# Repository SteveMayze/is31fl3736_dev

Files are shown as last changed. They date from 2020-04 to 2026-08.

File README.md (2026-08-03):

# IS31FL3736 Development Board

This project is to develop a prototype for reviewing the IS31FL3736 12×8 DOTS MATRIX LED DRIVER WITH INDIVIDUAL AUTO BREATH FUNCTION from [Integrated Silicon Solution, Inc](www.issi.com)
 The basic goals of this project is to create a simple board with an array of RGB leds to see what is involved to control the LEDs as per the writeup in the datasheet. Things of interest will be
 
 1. Simplicity of use (firmware)
 1. Simplicity of the layout
 1. The effective power consumption
 1. The footprint size.

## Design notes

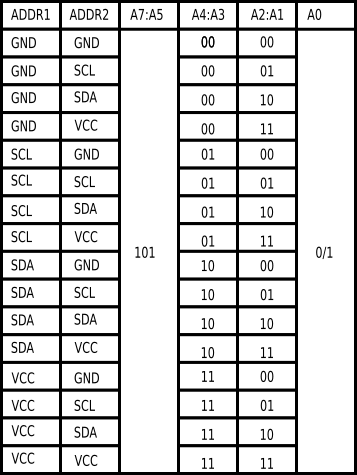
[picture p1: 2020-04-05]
Doc/AddressTable.png

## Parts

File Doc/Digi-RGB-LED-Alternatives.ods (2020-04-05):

Datenblätter | Abbildung | Digi-Key Teilenummer | Hersteller-Teilenummer | Hersteller | Beschreibung | Verfügbare Menge | Lagerbestand des Herstellers | Stückpreis (EUR) | @ qty | Mindestbestellmenge ist | Verpackung | Serie | Status der Komponente | Farbe | Konfiguration | Linsenfarbe | Linsentransparenz | Millicandela-Bewertung | Linsenstil | Linsengröße | Spannung - Forward (Vf) Typ | Strom - Test | Sichtwinkel | Montagetyp | Wellenlänge - dominant | Wellenlänge - Spitze | Funktionen | Gehäuse / Hülle | Gehäusetyp vom Lieferanten | Grösse / Dimension | Höhe (max.)
http://www.inolux-corp.com/datasheet/SMDLED/RGB%20Top%20View/IN-B101FCH.pdf | //media.digikey.com/Renders/Inolux/IN-B101FCH.JPG | 1830-1087-1-ND | IN-B101FCH | Inolux | LED RGB TOP VIEW SMD | 16764 | 0 | 0.39000 | 1 | 1 | Gurtabschnitt (CT) | - | Aktiv | Rot, Grün, Blau (RGB) | GemeinsameAnode | - | - | 58mcd Rot, 85mcd Grün, 17mcd Blau | Quadratisch mit flachem Oberteil | 1,00mm | 2,4V Rot, 3,4V Grün, 3,4V Blau | 10mA Rot, 10mA Grün, 10mA Blau | 140° | Oberflächenmontage | 621nm Rot, 531nm Grün, 470nm Blau | 629nm Rot, 520nm Grün, 480nm Blau | - | 0404 (1010 metrisch) | SMD | L x B: 1,00mm x 1,00mm | 0,75mm
http://www.inolux-corp.com/datasheet/SMDLED/RGB%20Top%20View/IN-B101FCH.pdf | //media.digikey.com/Renders/Inolux/IN-B101FCH.JPG | 1830-1087-6-ND | IN-B101FCH | Inolux | LED RGB TOP VIEW SMD | 16764 | 0 | Digi-Reel | 1 | 1 | Digi-Reel® | - | Aktiv | Rot, Grün, Blau (RGB) | GemeinsameAnode | - | - | 58mcd Rot, 85mcd Grün, 17mcd Blau | Quadratisch mit flachem Oberteil | 1,00mm | 2,4V Rot, 3,4V Grün, 3,4V Blau | 10mA Rot, 10mA Grün, 10mA Blau | 140° | Oberflächenmontage | 621nm Rot, 531nm Grün, 470nm Blau | 629nm Rot, 520nm Grün, 480nm Blau | - | 0404 (1010 metrisch) | SMD | L x B: 1,00mm x 1,00mm | 0,75mm
http://www.qt-brightek.com/datasheet/QBLP1515B-RGBA.pdf | //media.digikey.com/Renders/QT%20Brightek%20Renders/1516-1183-6.jpg | 1516-1183-1-ND | QBLP1515B-RGBA | QT Brightek (QTB) | LED RGB DIFFUSED 4PLCC SMD | 13659 | 0 | 0.79000 | 1 | 1 | Gurtabschnitt (CT) | - | Aktiv | Rot, Grün, Blau (RGB) | GemeinsameAnode | - | Diffundiert | 150mcd Rot, 300mcd Grün, 77mcd Blau | Quadratisch mit flachem Oberteil | - | 2V Rot, 3,1V Grün, 3,1V Blau | 10mA Rot, 10mA Grün, 10mA Blau | 120° | Oberflächenmontage | 622nm Rot, 523nm Grün, 467nm Blau | - | - | 4-SMD, J-Anschluss | 4-PLCC | L x B: 1,60mm x 1,50mm | 1,20mm
http://www.qt-brightek.com/datasheet/QBLP1515B-RGBA.pdf | //media.digikey.com/Renders/QT%20Brightek%20Renders/1516-1183-6.jpg | 1516-1183-6-ND | QBLP1515B-RGBA | QT Brightek (QTB) | LED RGB DIFFUSED 4PLCC SMD | 13659 | 0 | Digi-Reel | 1 | 1 | Digi-Reel® | - | Aktiv | Rot, Grün, Blau (RGB) | GemeinsameAnode | - | Diffundiert | 150mcd Rot, 300mcd Grün, 77mcd Blau | Quadratisch mit flachem Oberteil | - | 2V Rot, 3,1V Grün, 3,1V Blau | 10mA Rot, 10mA Grün, 10mA Blau | 120° | Oberflächenmontage | 622nm Rot, 523nm Grün, 467nm Blau | - | - | 4-SMD, J-Anschluss | 4-PLCC | L x B: 1,60mm x 1,50mm | 1,20mm
https://docs.broadcom.com/docs/HSMF-C129-DS100 | - | 516-4371-1-ND | HSMF-C129 | Broadcom Limited | LED RGB TOP MNT 0805 SMD | 5779 | 0 | 1.61000 | 1 | 1 | Gurtabschnitt (CT) | - | Aktiv | Rot, Grün, Blau (RGB) | GemeinsameAnode | - | - | - | Rechteckig mit flachem Oberteil | 1,40mm x 1,30mm | 2V Rot, 3,4V Grün, 3,4V Blau | 10mA Rot, 10mA Grün, 10mA Blau | 140° | Oberflächenmontage | 623nm Rot, 529nm Grün, 468nm Blau | 633nm Rot, 521nm Grün, 463nm Blau | - | 0805 (2012 metrisch) | 0805 | L x B: 2,00mm x 1,30mm | 0,60mm
https://docs.broadcom.com/docs/HSMF-C129-DS100 | - | 516-4371-6-ND | HSMF-C129 | Broadcom Limited | LED RGB TOP MNT 0805 SMD | 5779 | 0 | Digi-Reel | 1 | 1 | Digi-Reel® | - | Aktiv | Rot, Grün, Blau (RGB) | GemeinsameAnode | - | - | - | Rechteckig mit flachem Oberteil | 1,40mm x 1,30mm | 2V Rot, 3,4V Grün, 3,4V Blau | 10mA Rot, 10mA Grün, 10mA Blau | 140° | Oberflächenmontage | 623nm Rot, 529nm Grün, 468nm Blau | 633nm Rot, 521nm Grün, 463nm Blau | - | 0805 (2012 metrisch) | 0805 | L x B: 2,00mm x 1,30mm | 0,60mm
https://docs.broadcom.com/docs/HSMF-C125-DS100 | - | 516-4374-1-ND | HSMF-C125 | Broadcom Limited | LED RGB CHIP TOP MNT SMD | 5990 | 0 | 1.66000 | 1 | 1 | Gurtabschnitt (CT) | - | Aktiv | Rot, Grün, Blau (RGB) | Unabhängig | - | - | - | Rechteckig mit flachem Oberteil | 1,60mm x 1,15mm | 2,15V Rot, 3,415V Grün, 3,425V Blau | 10mA Rot, 10mA Grün, 10mA Blau | 130° Rot, 150° Grün, 150° Blau | Oberflächenmontage | 623nm Rot, 522nm Grün, 467nm Blau | 630nm Rot, 515nm Grün, 461nm Blau | - | 0606, konvex | - | L x B: 1,60mm x 1,60mm | 0,50mm
https://docs.broadcom.com/docs/HSMF-C125-DS100 | - | 516-4374-6-ND | HSMF-C125 | Broadcom Limited | LED RGB CHIP TOP MNT SMD | 5990 | 0 | Digi-Reel | 1 | 1 | Digi-Reel® | - | Aktiv | Rot, Grün, Blau (RGB) | Unabhängig | - | - | - | Rechteckig mit flachem Oberteil | 1,60mm x 1,15mm | 2,15V Rot, 3,415V Grün, 3,425V Blau | 10mA Rot, 10mA Grün, 10mA Blau | 130° Rot, 150° Grün, 150° Blau | Oberflächenmontage | 623nm Rot, 522nm Grün, 467nm Blau | 630nm Rot, 515nm Grün, 461nm Blau | - | 0606, konvex | - | L x B: 1,60mm x 1,60mm | 0,50mm
http://www.qt-brightek.com/datasheet/QBLP1515B-RGBA.pdf | //media.digikey.com/Renders/QT%20Brightek%20Renders/1516-1183-6.jpg | 1516-1183-2-ND | QBLP1515B-RGBA | QT Brightek (QTB) | LED RGB DIFFUSED 4PLCC SMD | 10500 | 0 | 0.23585 | 0 | 3500 | Gurt auf Rolle (Tape and Reel - TR) | - | Aktiv | Rot, Grün, Blau (RGB) | GemeinsameAnode | - | Diffundiert | 150mcd Rot, 300mcd Grün, 77mcd Blau | Quadratisch mit flachem Oberteil | - | 2V Rot, 3,1V Grün, 3,1V Blau | 10mA Rot, 10mA Grün, 10mA Blau | 120° | Oberflächenmontage | 622nm Rot, 523nm Grün, 467nm Blau | - | - | 4-SMD, J-Anschluss | 4-PLCC | L x B: 1,60mm x 1,50mm | 1,20mm
https://docs.broadcom.com/docs/HSMF-C125-DS100 | - | 516-4374-2-ND | HSMF-C125 | Broadcom Limited | LED RGB CHIP TOP MNT SMD | 4000 | 0 | 0.55045 | 0 | 2000 | Gurt auf Rolle (Tape and Reel - TR) | - | Aktiv | Rot, Grün, Blau (RGB) | Unabhängig | - | - | - | Rechteckig mit flachem Oberteil | 1,60mm x 1,15mm | 2,15V Rot, 3,415V Grün, 3,425V Blau | 10mA Rot, 10mA Grün, 10mA Blau | 130° Rot, 150° Grün, 150° Blau | Oberflächenmontage | 623nm Rot, 522nm Grün, 467nm Blau | 630nm Rot, 515nm Grün, 461nm Blau | - | 0606, konvex | - | L x B: 1,60mm x 1,60mm | 0,50mm
https://docs.broadcom.com/docs/HSMF-C129-DS100 | - | 516-4371-2-ND | HSMF-C129 | Broadcom Limited | LED RGB TOP MNT 0805 SMD | 4000 | 0 | 0.59781 | 0 | 2000 | Gurt auf Rolle (Tape and Reel - TR) | - | Aktiv | Rot, Grün, Blau (RGB) | GemeinsameAnode | - | - | - | Rechteckig mit flachem Oberteil | 1,40mm x 1,30mm | 2V Rot, 3,4V Grün, 3,4V Blau | 10mA Rot, 10mA Grün, 10mA Blau | 140° | Oberflächenmontage | 623nm Rot, 529nm Grün, 468nm Blau | 633nm Rot, 521nm Grün, 463nm Blau | - | 0805 (2012 metrisch) | 0805 | L x B: 2,00mm x 1,30mm | 0,60mm

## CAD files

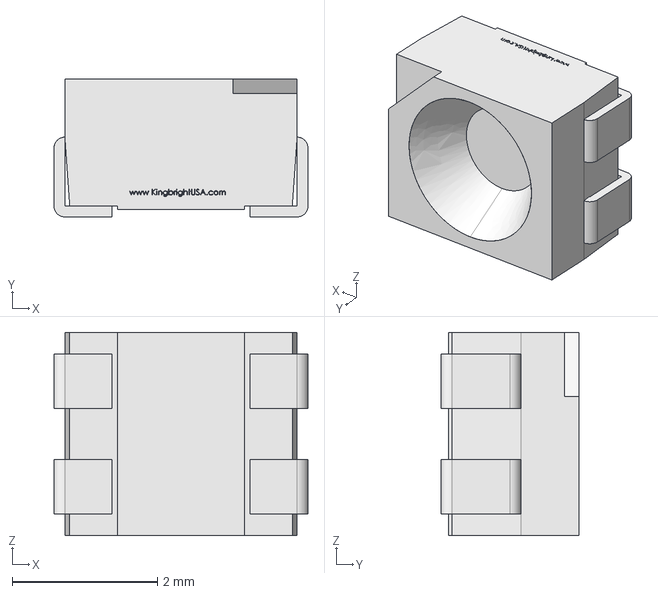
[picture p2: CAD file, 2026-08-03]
Doc/3d/xx.step
3.50 x 1.90 x 2.80 mm

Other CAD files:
Doc/3d/AAA3528.sldprt
Doc/3d/AAA3528.FCStd
Doc/3d/AAA3528.IGS

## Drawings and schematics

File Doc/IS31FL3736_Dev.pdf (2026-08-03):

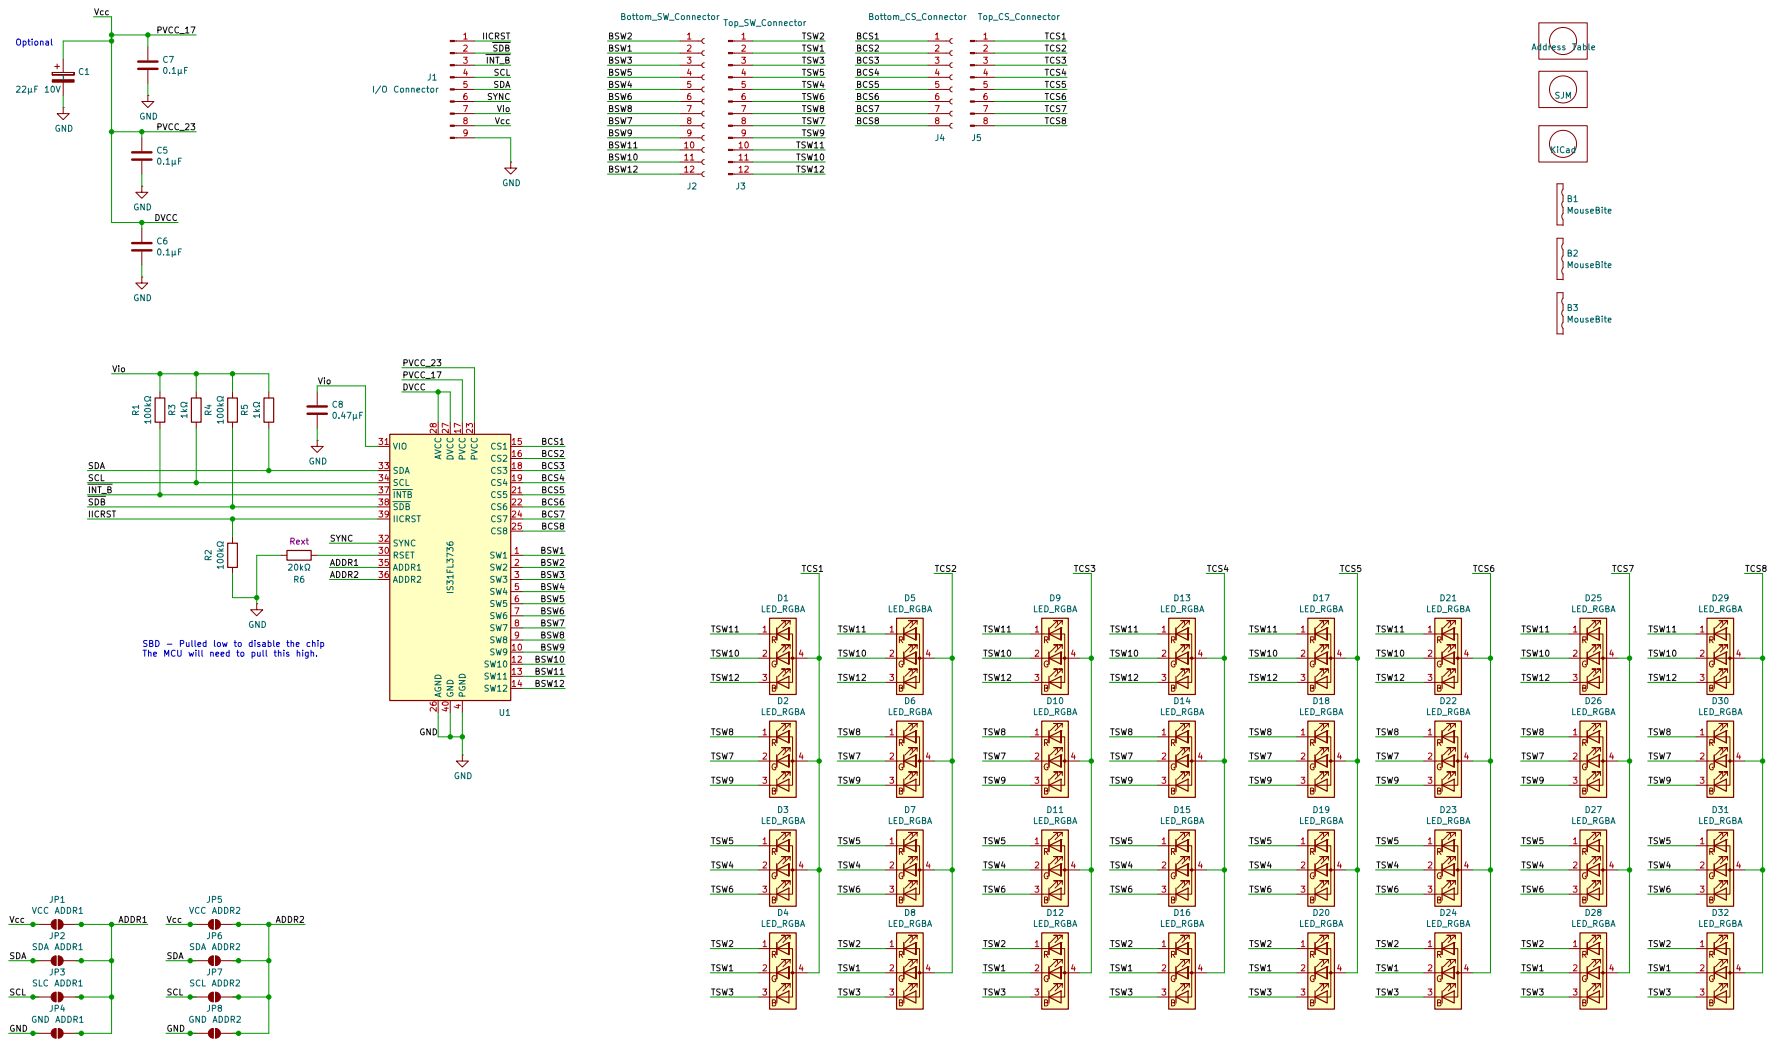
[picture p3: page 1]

SBD - Pulled low to disable the chip
The MCU will need to pull this high.

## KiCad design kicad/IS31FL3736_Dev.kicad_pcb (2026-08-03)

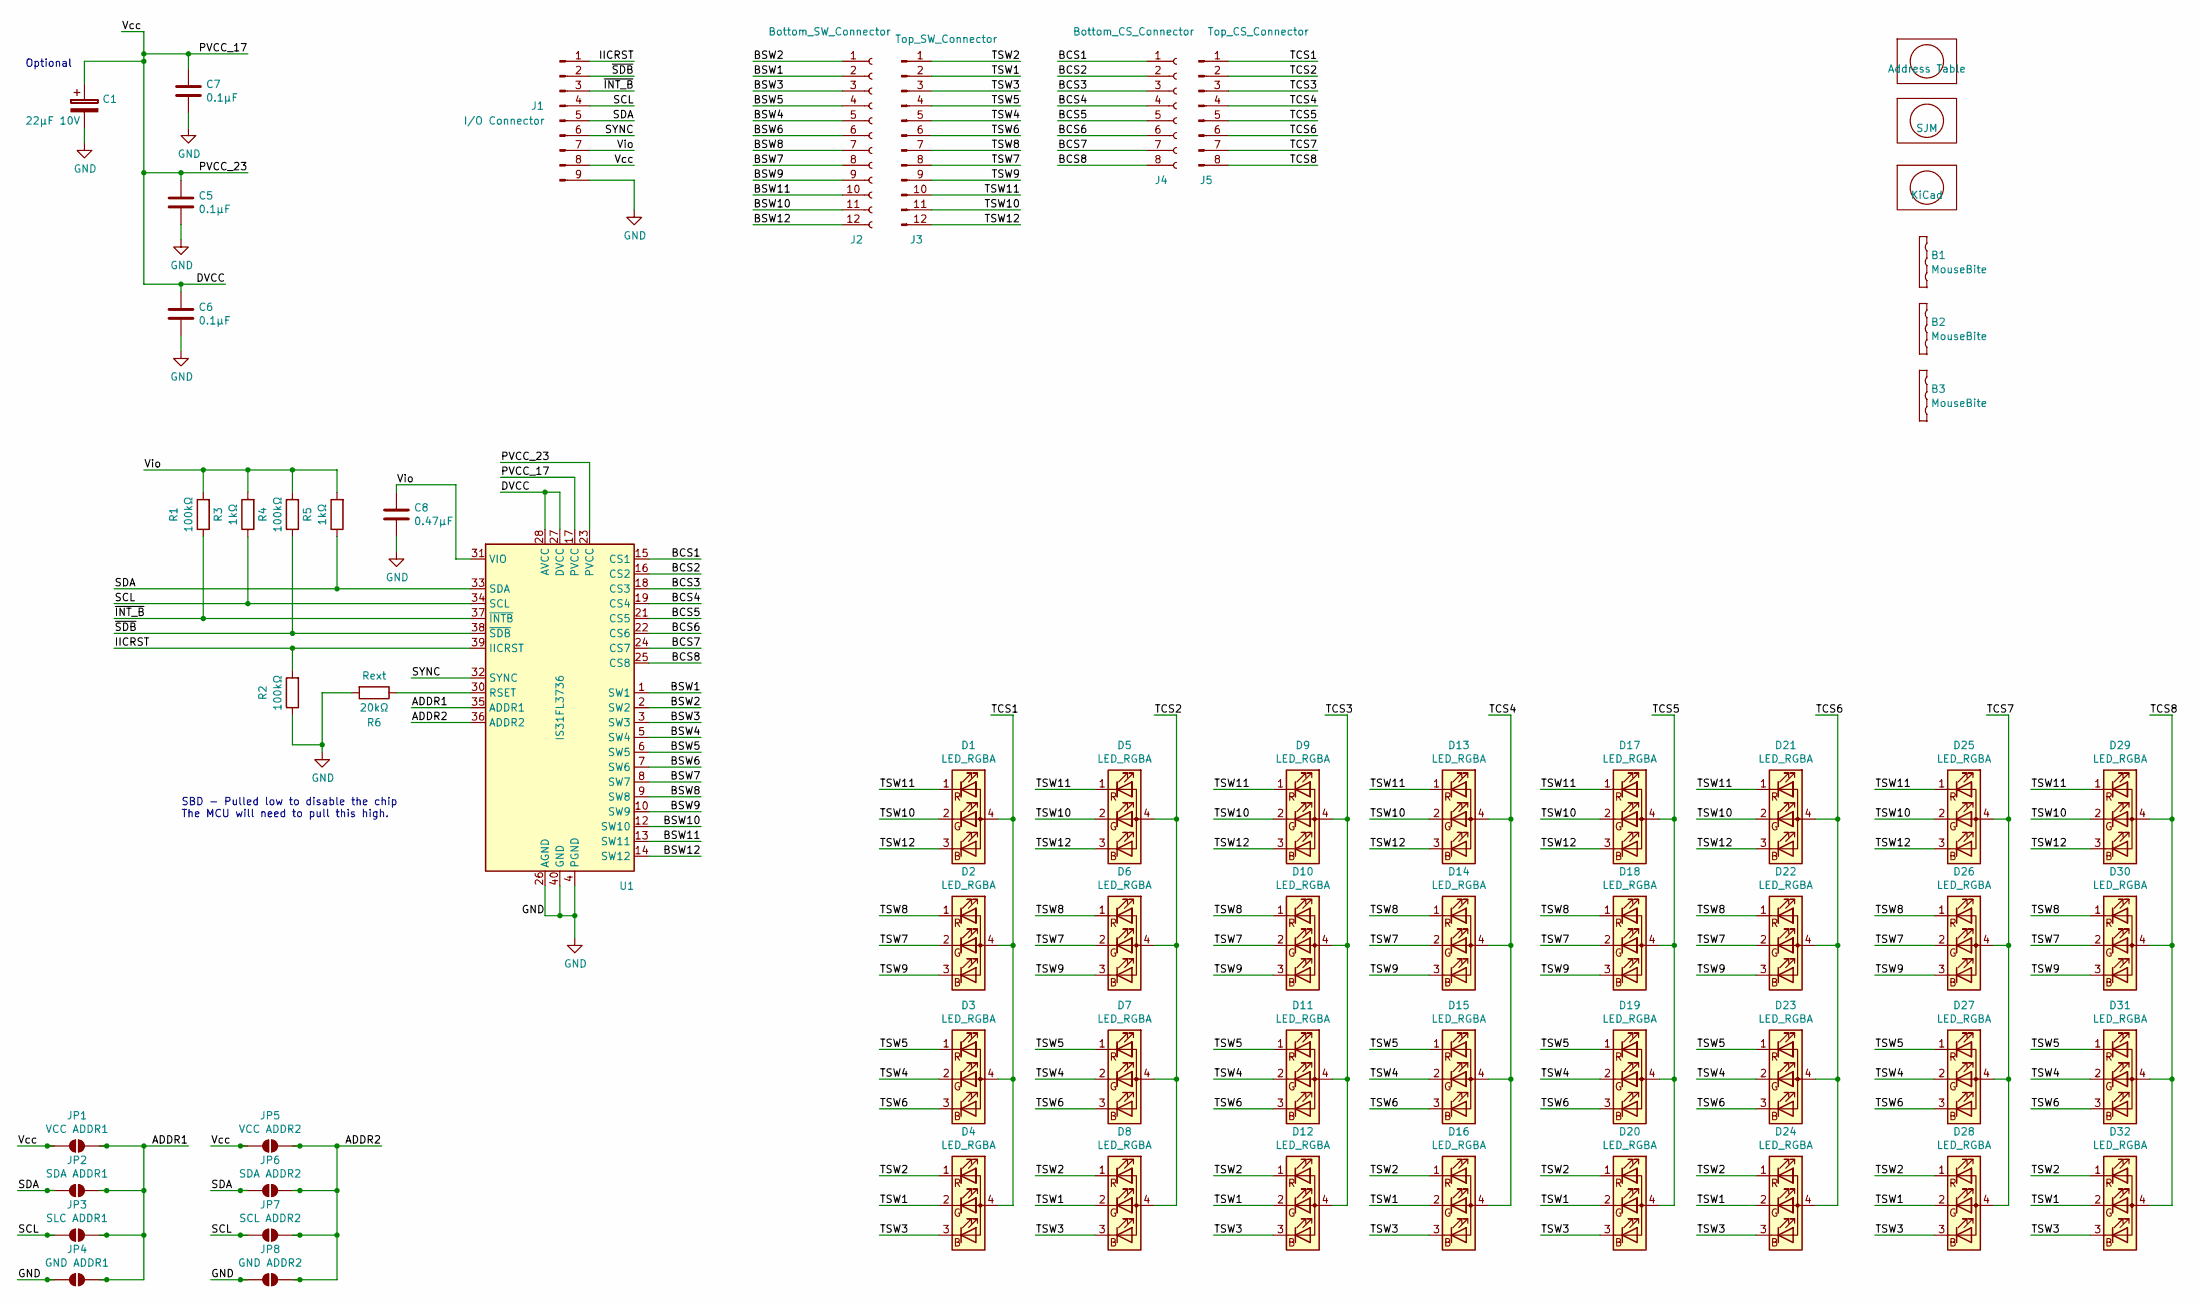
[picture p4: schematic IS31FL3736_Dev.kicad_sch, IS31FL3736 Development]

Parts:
B1, B2, B3: MouseBite; MouseBites
C1: 22μF 10V; CP_EIA-2012-15_AVX-P
C5, C6, C7: 0.1μF; C_0805_2012Metric
C8: 0.47μF; C_0805_2012Metric
D1, D2, D3, D4, D5, D6, D7, D8, D9, D10, D11, D12, D13, D14, D15, D16, D17, D18, D19, D20, D21, D22, D23, D24, D25, D26, D27, D28, D29, D30, D31, D32: LED_RGBA; LED_RGB_4-PLCC; MPN AAA3528LSEEZGKQBKS
J1: I/O Connector; PinHeader_1x09_P2.54mm_Horizontal
J2: Bottom_SW_Connector; PinSocket_1x12_P2.54mm_Vertical
J3: Top_SW_Connector; PinHeader_1x12_P2.54mm_Vertical
J4: Bottom_CS_Connector; PinSocket_1x08_P2.54mm_Vertical
J5: Top_CS_Connector; PinHeader_1x08_P2.54mm_Vertical
JP1: VCC ADDR1; SolderJumper-2_P1.3mm_Open_RoundedPad1.0x1.5mm
JP2: SDA ADDR1; SolderJumper-2_P1.3mm_Open_RoundedPad1.0x1.5mm
JP3: SLC ADDR1; SolderJumper-2_P1.3mm_Open_RoundedPad1.0x1.5mm
JP4: GND ADDR1; SolderJumper-2_P1.3mm_Open_RoundedPad1.0x1.5mm
JP5: VCC ADDR2; SolderJumper-2_P1.3mm_Open_RoundedPad1.0x1.5mm
JP6: SDA ADDR2; SolderJumper-2_P1.3mm_Open_RoundedPad1.0x1.5mm
JP7: SCL ADDR2; SolderJumper-2_P1.3mm_Open_RoundedPad1.0x1.5mm
JP8: GND ADDR2; SolderJumper-2_P1.3mm_Open_RoundedPad1.0x1.5mm
Lg1: SJM; MyBasic_rounded_50_1
Lg2: KiCad; KiCad-Logo2_5mm_SilkScreen
Lg3: Address Table; Address_Table
R1, R2, R4: 100kΩ; R_0805_2012Metric
R3, R5: 1kΩ; R_0805_2012Metric
R6: 20kΩ; R_0805_2012Metric
U1: IS31FL3736; QFN-40-1EP_5x5mm_P0.4mm_EP3.6x3.6mm; MPN IS31FL3736

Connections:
/ADDR1: JP1.2 (B), JP2.2 (B), JP3.2 (B), JP4.2 (B), U1.35 (ADDR1)
/ADDR2: JP5.2 (B), JP6.2 (B), JP7.2 (B), JP8.2 (B), U1.36 (ADDR2)
/BCS1: J4.1, U1.15 (CS1)
/BCS2: J4.2, U1.16 (CS2)
/BCS3: J4.3, U1.18 (CS3)
/BCS4: J4.4, U1.19 (CS4)
/BCS5: J4.5, U1.21 (CS5)
/BCS6: J4.6, U1.22 (CS6)
/BCS7: J4.7, U1.24 (CS7)
/BCS8: J4.8, U1.25 (CS8)
/BSW1: J2.2, U1.1 (SW1)
/BSW2: J2.1, U1.2 (SW2)
/BSW3: J2.3, U1.3 (SW3)
/BSW4: J2.5, U1.5 (SW4)
/BSW5: J2.4, U1.6 (SW5)
/BSW6: J2.6, U1.7 (SW6)
/BSW7: J2.8, U1.8 (SW7)
/BSW8: J2.7, U1.9 (SW8)
/BSW9: J2.9, U1.10 (SW9)
/BSW10: J2.11, U1.12 (SW10)
/BSW11: J2.10, U1.13 (SW11)
/BSW12: J2.12, U1.14 (SW12)
/DVCC: C1.1, C5.1, C6.1, C7.1, J1.8, JP1.1 (A), JP5.1 (A), U1.17 (PVCC), U1.23 (PVCC), U1.27 (DVCC), U1.28 (AVCC)
/IICRST: J1.1, R2.2, U1.39 (IICRST)
/SCL: J1.4, JP3.1 (A), JP7.1 (A), R3.1, U1.34 (SCL)
/SDA: J1.5, JP2.1 (A), JP6.1 (A), R5.1, U1.33 (SDA)
/SYNC: J1.6, U1.32 (SYNC)
/TCS1: D1.4 (A), D2.4 (A), D3.4 (A), D4.4 (A), J5.1
/TCS2: D5.4 (A), D6.4 (A), D7.4 (A), D8.4 (A), J5.2
/TCS3: D9.4 (A), D10.4 (A), D11.4 (A), D12.4 (A), J5.3
/TCS4: D13.4 (A), D14.4 (A), D15.4 (A), D16.4 (A), J5.4
/TCS5: D17.4 (A), D18.4 (A), D19.4 (A), D20.4 (A), J5.5
/TCS6: D21.4 (A), D22.4 (A), D23.4 (A), D24.4 (A), J5.6
/TCS7: D25.4 (A), D26.4 (A), D27.4 (A), D28.4 (A), J5.7
/TCS8: D29.4 (A), D30.4 (A), D31.4 (A), D32.4 (A), J5.8
/TSW1: D4.2 (GK), D8.2 (GK), D12.2 (GK), D16.2 (GK), D20.2 (GK), D24.2 (GK), D28.2 (GK), D32.2 (GK), J3.2
/TSW2: D4.1 (RK), D8.1 (RK), D12.1 (RK), D16.1 (RK), D20.1 (RK), D24.1 (RK), D28.1 (RK), D32.1 (RK), J3.1
/TSW3: D4.3 (BK), D8.3 (BK), D12.3 (BK), D16.3 (BK), D20.3 (BK), D24.3 (BK), D28.3 (BK), D32.3 (BK), J3.3
/TSW4: D3.2 (GK), D7.2 (GK), D11.2 (GK), D15.2 (GK), D19.2 (GK), D23.2 (GK), D27.2 (GK), D31.2 (GK), J3.5
/TSW5: D3.1 (RK), D7.1 (RK), D11.1 (RK), D15.1 (RK), D19.1 (RK), D23.1 (RK), D27.1 (RK), D31.1 (RK), J3.4
/TSW6: D3.3 (BK), D7.3 (BK), D11.3 (BK), D15.3 (BK), D19.3 (BK), D23.3 (BK), D27.3 (BK), D31.3 (BK), J3.6
/TSW7: D2.2 (GK), D6.2 (GK), D10.2 (GK), D14.2 (GK), D18.2 (GK), D22.2 (GK), D26.2 (GK), D30.2 (GK), J3.8
/TSW8: D2.1 (RK), D6.1 (RK), D10.1 (RK), D14.1 (RK), D18.1 (RK), D22.1 (RK), D26.1 (RK), D30.1 (RK), J3.7
/TSW9: D2.3 (BK), D6.3 (BK), D10.3 (BK), D14.3 (BK), D18.3 (BK), D22.3 (BK), D26.3 (BK), D30.3 (BK), J3.9
/TSW10: D1.2 (GK), D5.2 (GK), D9.2 (GK), D13.2 (GK), D17.2 (GK), D21.2 (GK), D25.2 (GK), D29.2 (GK), J3.11
/TSW11: D1.1 (RK), D5.1 (RK), D9.1 (RK), D13.1 (RK), D17.1 (RK), D21.1 (RK), D25.1 (RK), D29.1 (RK), J3.10
/TSW12: D1.3 (BK), D5.3 (BK), D9.3 (BK), D13.3 (BK), D17.3 (BK), D21.3 (BK), D25.3 (BK), D29.3 (BK), J3.12
/Vio: C8.1, J1.7, R1.2, R3.2, R4.2, R5.2, U1.31 (VIO)
/~INT_B: J1.3, R1.1, U1.37 (~INTB)
/~SDB: J1.2, R4.1, U1.38 (~SDB)
GND: C1.2, C5.2, C6.2, C7.2, C8.2, J1.9, JP4.1 (A), JP8.1 (A), R2.1, R6.2, U1.4 (PGND), U1.11 (PGND), U1.26 (AGND), U1.40 (GND), U1.41 (GND)
unnamed: R6.1, U1.30 (RSET)

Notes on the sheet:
SBD - Pulled low to disable the chip The MCU will need to pull this high.
Optional

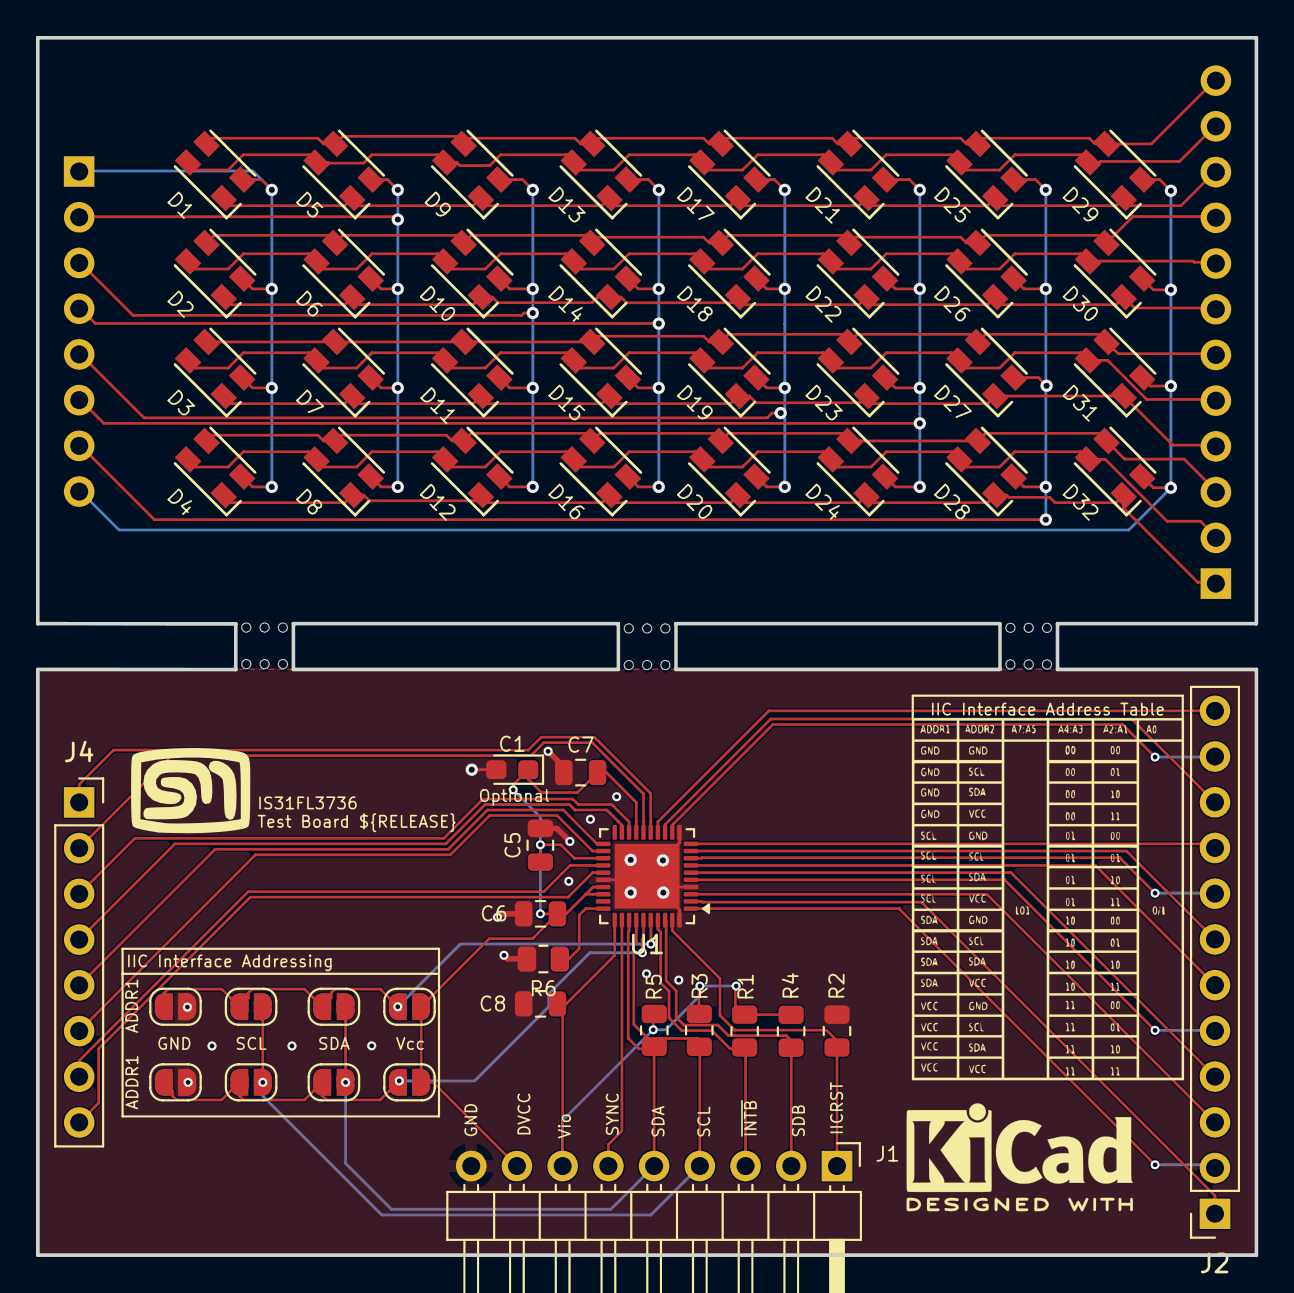
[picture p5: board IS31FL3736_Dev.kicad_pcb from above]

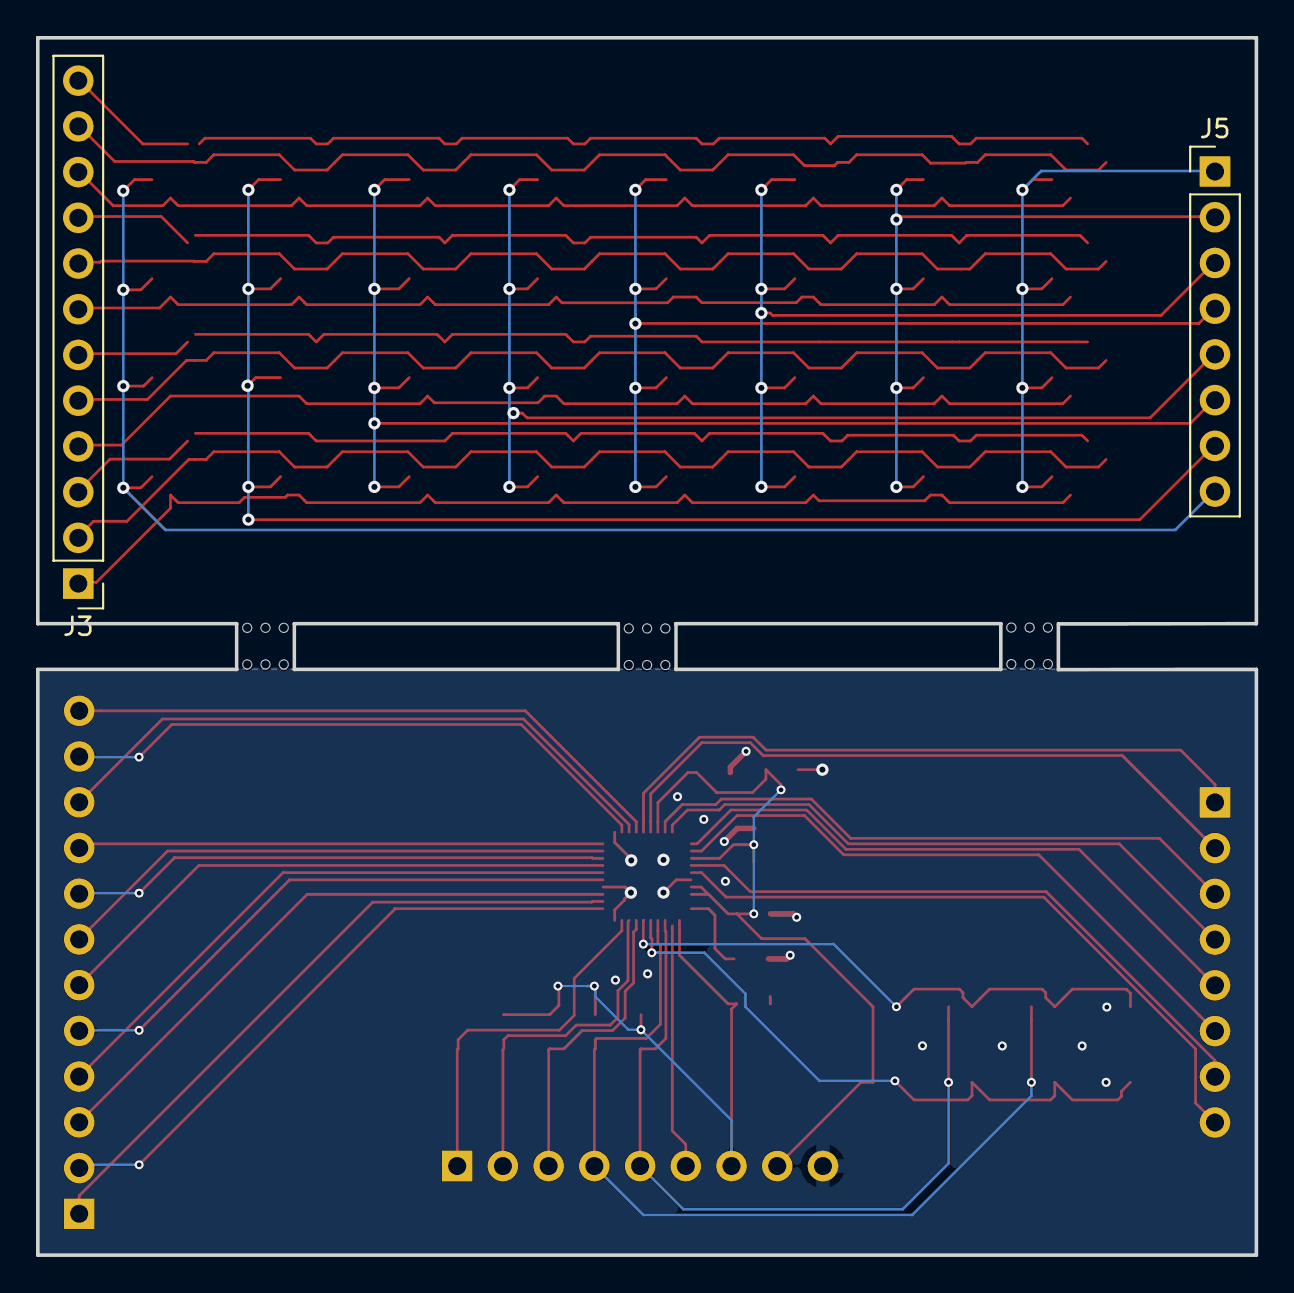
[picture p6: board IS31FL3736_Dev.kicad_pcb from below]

Board: 2 copper layers, 67.7 x 67.6 mm, 63 parts (2 on the bottom side), 52 nets.

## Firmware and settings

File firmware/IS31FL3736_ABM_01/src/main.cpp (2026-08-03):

#include <Arduino.h>

#include<Wire.h>
#include<avr/pgmspace.h>
#define Addr_GND_GND 0xa0//AD1 open (R7 pull-low), ADDR2=GND
#define Addr_GND_VCC 0xa6//AD1 = VIO, ADDR2=GND
#define Addr_GND_SCL 0xa2//AD1 = SCL, ADDR2=GND
#define Addr_GND_SDA 0xa4//AD1 = SDA, ADDR2=GND

#define DISPLAY_ADDR Addr_GND_GND

#define RED 0
#define ORANGE 1
#define YELLOW 2
#define SPRING_GREEN 3
#define GREEN 4
#define TURQUOISE 5
#define CYAN 6
#define OCEAN 7
#define BLUE 8
#define VIOLET 9
#define MAGENTA 10
#define RASPBERRY 11


#define IS31FL3736_LED_RED 1
#define IS31FL3736_LED_GREEN 2
#define IS31FL3736_LED_BLUE 3

#define ROWS 4
#define COLUMNS 8

#define BLUE_LED 0
#define GREEN_LED 1
#define RED_LED 2




uint8_t pwm_reg[12][16];
uint8_t abm_reg[12][16];
uint8_t abm_ctl_reg[12];

uint8_t raddr = 0;
uint8_t caddr = 0;

#define ABMCR_3_LTA 0x00
#define ABMCR_3_LTB 0x00
#define ABMCR_3_LB 0x04
#define ABMCR_3_LE 0x06

// PG 3

#define IS31FL3736_CFG     0x00
#define IS31FL3736_GCC     0x01
#define IS31FL3736_ABM_1_1 0x02
#define IS31FL3736_ABM_1_2 0x03
#define IS31FL3736_ABM_1_3 0x04
#define IS31FL3736_ABM_1_4 0x05
#define IS31FL3736_ABM_2_1 0x06
#define IS31FL3736_ABM_2_2 0x07
#define IS31FL3736_ABM_2_3 0x08
#define IS31FL3736_ABM_2_4 0x09
#define IS31FL3736_ABM_3_1 0x0A
#define IS31FL3736_ABM_3_2 0x0B
#define IS31FL3736_ABM_3_3 0x0C
#define IS31FL3736_ABM_3_4 0x0D
#define IS31FL3736_TIME_UPDATE 0x0E

#define ABM_LB_BIT 0x04 // Loop times - Endless

#define ABM_LB_T1 0x00 // Loop begin from T1
#define ABM_LB_T2 0x01 // Loop begin from T2
#define ABM_LB_T3 0x02 // Loop begin from T3
#define ABM_LB_T4 0x03 // Loop begin from T4

#define ABM_LE_BIT 0x06 // Loop times - Endless

#define ABM_LE_T3 0x00 // Loop end from T3 // i.e. off state
#define ABM_LE_T1 0x01 // Loop end from T1 // i.e. on state

#define ABM_LTA_BIT 0x00 // Loop times - Endless

#define ABM_LTA_ENDLESS 0x00 // Loop times - Endless
#define ABM_LTA_1 0x01 // Loop times - 1
#define ABM_LTA_2 0x02 // Loop times - 2
#define ABM_LTA_3 0x03 // Loop times - 3
#define ABM_LTA_4 0x04 // Loop times - 4
#define ABM_LTA_5 0x05 // Loop times - 5
#define ABM_LTA_6 0x06 // Loop times - 6
#define ABM_LTA_7 0x07 // Loop times - 7
#define ABM_LTA_8 0x08 // Loop times - 8
#define ABM_LTA_9 0x09 // Loop times - 9
#define ABM_LTA_10 0x0A // Loop times - 10
#define ABM_LTA_11 0x0B // Loop times - 11
#define ABM_LTA_12 0x0C // Loop times - 12
#define ABM_LTA_13 0x0F // Loop times - 13
#define ABM_LTA_14 0x0E // Loop times - 14
#define ABM_LTA_15 0x0F // Loop times - 15

#define ABM_LTB_BIT 0x00 // Loop times - Endless


#define T1_BITS 0x05
// Register 1 of ABM-x
#define T1_0021 0x00 // 0.21s
#define T1_0042 0x01 // 0.42s
#define T1_0084 0x02 // 0.84s
#define T1_0168 0x03 // 1.68s
#define T1_0336 0x04 // 3.36s
#define T1_0672 0x05 // 6.72s
#define T1_1344 0x06 // 13.44s
#define T1_2688 0x07 // 26.88s

#define T2_BITS 0x01
#define T2_00000 0x00 //0s
#define T2_00021 0x01 // 0.21s
#define T2_00042 0x02 // 0.42s
#define T2_00084 0x03 // 0.84s
#define T2_00168 0x04 // 1.68s
#define T2_00336 0x05 // 3.36s
#define T2_00672 0x06 // 6.72s
#define T2_01344 0x07 // 13.44s
#define T2_02688 0x08 // 26.88s

// Register 2 of ABM-x
#define T3_BITS 0x05
#define T3_0021 0x00 // 0.21s
#define T3_0042 0x01 // 0.42s
#define T3_0084 0x02 // 0.84s
#define T3_0168 0x03 // 1.68s
#define T3_0336 0x04 // 3.36s
#define T3_0672 0x05 // 6.72s
#define T3_1344 0x06 // 13.44s
#define T3_2688 0x07 // 26.88s

#define T4_BITS 0x01
#define T4_00000 0x00 //0s
#define T4_00021 0x01 // 0.21s
#define T4_00042 0x02 // 0.42s
#define T4_00084 0x03 // 0.84s
#define T4_00168 0x04 // 1.68s
#define T4_00336 0x05 // 3.36s
#define T4_00672 0x06 // 6.72s
#define T4_01344 0x07 // 13.44s
#define T4_02688 0x08 // 26.88s
#define T4_05376 0x09 // 53.76s
#define T4_10752 0x0A // 107.52s



static const int heartbeat = 13;

/*
 Calculates the SW register address from the row number
 */
uint8_t IS31FL3736_row_address(int8_t row, uint8_t colour) {
  return (uint8_t) 3 * (row - 1) + colour;
}

uint8_t IS31FL3736_column_bit() {
  return -1;
}

void IS_IIC_WriteByte(uint8_t Dev_Add, uint8_t Reg_Add, uint8_t Reg_Dat)
{
  Wire.beginTransmission(Dev_Add/2); // transmit to device address
  Wire.write(Reg_Add); // sends register address
  Wire.write(Reg_Dat); // sends register data
  Wire.endTransmission(); // stop transmitting
}


void IS31FL3736_pwm_init(void)//white LED
{
  uint8_t i;
  IS_IIC_WriteByte(DISPLAY_ADDR,0xFE,0xc5);//Unlock FDh
  IS_IIC_WriteByte(DISPLAY_ADDR,0xFD,0x03);//Turn to page 3: function registers
  IS_IIC_WriteByte(DISPLAY_ADDR,0x00,0x00);//Enable software shutdown
  IS_IIC_WriteByte(DISPLAY_ADDR,0xFE,0xc5);//Unlock FDh
  IS_IIC_WriteByte(DISPLAY_ADDR,0xFD,0x00);// Turn to page 0: control registers
  for(i=0;i<0x18;i++) {
    IS_IIC_WriteByte(DISPLAY_ADDR,i,0xFF);// Enable all LEDs
  }
  //can use buffer write type as figure 7 in datasheet
  IS_IIC_WriteByte(DISPLAY_ADDR,0xFE,0xc5);//unlock FDh
  IS_IIC_WriteByte(DISPLAY_ADDR,0xFD,0x01);//Turn to page 1: PWM registers
  for(i=0;i<192;i++) {
    IS_IIC_WriteByte(DISPLAY_ADDR,i,0x00);//Set PWM data to 0
  }
  //can use buffer write type as figure 7 in datasheet
  IS_IIC_WriteByte(DISPLAY_ADDR,0xFE,0xc5);//unlock FDh
  IS_IIC_WriteByte(DISPLAY_ADDR,0xFD,0x03);//Turn to page 3: function registers
  IS_IIC_WriteByte(DISPLAY_ADDR,0x00,0x01);//Release software shutdown to normal operation
  IS_IIC_WriteByte(DISPLAY_ADDR,0x01,0x1f);//global current
}

void by_rows() {
  for ( uint8_t row = 0; row < ROWS; row++) {
    for( uint8_t column = 0; column < COLUMNS; column++){
      raddr = row*3;
      caddr = column *2;
      switch(row){
        case 0:
        abm_reg[raddr + RED_LED][caddr] = 0x01;
        abm_reg[raddr + GREEN_LED][caddr] = 0x02;
        abm_reg[raddr + BLUE_LED][caddr] = 0x03;
        break;
        case 1:
        abm_reg[raddr + RED_LED][caddr] = 0x02;
        abm_reg[raddr + GREEN_LED][caddr] = 0x03;
        abm_reg[raddr + BLUE_LED][caddr] = 0x01;
        break;
        case 2:
        abm_reg[raddr + RED_LED][caddr] = 0x03;
        abm_reg[raddr + GREEN_LED][caddr] = 0x01;
        abm_reg[raddr + BLUE_LED][caddr] = 0x02;
        break;
        case 3:
        abm_reg[raddr + RED_LED][caddr] = 0x01;
        abm_reg[raddr + GREEN_LED][caddr] = 0x02;
        abm_reg[raddr + BLUE_LED][caddr] = 0x03;
        break;
      }
    }
  }

}

void by_columns_(){
  for ( uint8_t row = 0; row < ROWS; row++) {
    for( uint8_t column = 0; column < COLUMNS; column++){
      raddr = row*3;
      caddr = column *2;

      // abm_reg[raddr + RED_LED][caddr] = 0x01;
      // abm_reg[raddr + GREEN_LED][caddr] = 0x02;
      // abm_reg[raddr + BLUE_LED][caddr] = 0x03;

      switch(column){
        case 0:
        abm_reg[raddr + RED_LED][caddr] = 0x01;
        abm_reg[raddr + GREEN_LED][caddr] = 0x02;
        abm_reg[raddr + BLUE_LED][caddr] = 0x03;
        break;
        case 1:
        abm_reg[raddr + RED_LED][caddr] = 0x02;
        abm_reg[raddr + GREEN_LED][caddr] = 0x03;
        abm_reg[raddr + BLUE_LED][caddr] = 0x01;
        break;
        case 2:
        abm_reg[raddr + RED_LED][caddr] = 0x03;
        abm_reg[raddr + GREEN_LED][caddr] = 0x02;
        abm_reg[raddr + BLUE_LED][caddr] = 0x01;
        break;
        case 3:
        abm_reg[raddr + RED_LED][caddr] = 0x01;
        abm_reg[raddr + GREEN_LED][caddr] = 0x02;
        abm_reg[raddr + BLUE_LED][caddr] = 0x03;
        break;
        case 4:
        abm_reg[raddr + RED_LED][caddr] = 0x02;
        abm_reg[raddr + GREEN_LED][caddr] = 0x03;
        abm_reg[raddr + BLUE_LED][caddr] = 0x01;
        break;
        case 5:
        abm_reg[raddr + RED_LED][caddr] = 0x03;
        abm_reg[raddr + GREEN_LED][caddr] = 0x01;
        abm_reg[raddr + BLUE_LED][caddr] = 0x02;
        break;
        case 6:
        abm_reg[raddr + RED_LED][caddr] = 0x01;
        abm_reg[raddr + GREEN_LED][caddr] = 0x02;
        abm_reg[raddr + BLUE_LED][caddr] = 0x03;
        break;
        case 7:
        abm_reg[raddr + RED_LED][caddr] = 0x02;
        abm_reg[raddr + GREEN_LED][caddr] = 0x03;
        abm_reg[raddr + BLUE_LED][caddr] = 0x01;
        break;
      }
    }
  }

}

void by_columns(){
  for ( uint8_t row = 0; row < ROWS; row++) {
    for( uint8_t column = 0; column < COLUMNS; column++){
      raddr = row*3;
      caddr = column *2;

      // abm_reg[raddr + RED_LED][caddr] = 0x01;
      // abm_reg[raddr + GREEN_LED][caddr] = 0x02;
      // abm_reg[raddr + BLUE_LED][caddr] = 0x03;
        abm_reg[raddr + RED_LED][caddr] = 0x01;
        abm_reg[raddr + GREEN_LED][caddr] = 0x02;
        abm_reg[raddr + BLUE_LED][caddr] = 0x03;
    }
  }

}


void IS31FL3736_abm_init(void)//white LED
{
  uint8_t i;
  IS_IIC_WriteByte(DISPLAY_ADDR, 0xFE, 0xc5); //Unlock FDh
  IS_IIC_WriteByte(DISPLAY_ADDR, 0xFD, 0x00); // Turn to page 0: LED Control
  for(i=0;i<0x18;i++) {
    IS_IIC_WriteByte(DISPLAY_ADDR, i, 0xFF); // Enable all LEDs
  }


  by_columns();

  IS_IIC_WriteByte(DISPLAY_ADDR,0xFE,0xc5);//unlock FDh
  IS_IIC_WriteByte(DISPLAY_ADDR,0xFD,0x02);//Turn to page 2: ABM registers
  uint8_t pwmAddr = 0;
  for ( uint8_t i=0; i<12; i++) {
    for( uint8_t j=0; j<16; j=j+2) {
      IS_IIC_WriteByte(DISPLAY_ADDR, pwmAddr, abm_reg[i][j]);//Set PWM data to 0
      pwmAddr = pwmAddr+2;
    }
  }

  IS_IIC_WriteByte(DISPLAY_ADDR,0xFE,0xc5);//unlock FDh
  IS_IIC_WriteByte(DISPLAY_ADDR,0xFD,0x03);//Turn to page 3: Config Registers
  IS_IIC_WriteByte(DISPLAY_ADDR,0x00,0x00); //Enable software shutdown
  uint8_t timing_1 = T1_0021<<T1_BITS|T2_00021<<T2_BITS;
  uint8_t timing_2 = T3_0021<<T3_BITS|T4_00021<<T4_BITS;
  uint8_t timing_3 = T1_0021<<T1_BITS|T2_00021<<T2_BITS;
  uint8_t timing_4 = T3_0021<<T3_BITS|T4_00021<<T4_BITS;
  IS_IIC_WriteByte(DISPLAY_ADDR, IS31FL3736_ABM_1_1, timing_1);
  IS_IIC_WriteByte(DISPLAY_ADDR, IS31FL3736_ABM_1_2, timing_2);
  IS_IIC_WriteByte(DISPLAY_ADDR, IS31FL3736_ABM_1_3, ABM_LE_T3<<ABM_LE_BIT|ABM_LB_T1<<ABM_LB_BIT|ABM_LTA_ENDLESS<<ABM_LTA_BIT);
  IS_IIC_WriteByte(DISPLAY_ADDR, IS31FL3736_ABM_1_4, 0b00000000);

  IS_IIC_WriteByte(DISPLAY_ADDR, IS31FL3736_ABM_2_1, timing_3);
  IS_IIC_WriteByte(DISPLAY_ADDR, IS31FL3736_ABM_2_2, timing_4);
  IS_IIC_WriteByte(DISPLAY_ADDR, IS31FL3736_ABM_2_3, ABM_LE_T3<<ABM_LE_BIT|ABM_LB_T3<<ABM_LB_BIT|ABM_LTA_ENDLESS<<ABM_LTA_BIT);
  IS_IIC_WriteByte(DISPLAY_ADDR, IS31FL3736_ABM_2_4, 0b00000000);

  IS_IIC_WriteByte(DISPLAY_ADDR, IS31FL3736_ABM_3_1, timing_1);
  IS_IIC_WriteByte(DISPLAY_ADDR, IS31FL3736_ABM_3_2, timing_2);
  IS_IIC_WriteByte(DISPLAY_ADDR, IS31FL3736_ABM_3_3, ABM_LE_T3<<ABM_LE_BIT|ABM_LB_T4<<ABM_LB_BIT|ABM_LTA_ENDLESS<<ABM_LTA_BIT);
  IS_IIC_WriteByte(DISPLAY_ADDR, IS31FL3736_ABM_3_4, 0b00000000);

  //can use buffer write type as figure 7 in datasheet
  IS_IIC_WriteByte(DISPLAY_ADDR,0xFE,0xc5); //Unlock FDh
  IS_IIC_WriteByte(DISPLAY_ADDR,0xFD,0x03); //Turn to page 3: function registers
  IS_IIC_WriteByte(DISPLAY_ADDR,0x01,0x1f); //global current
  IS_IIC_WriteByte(DISPLAY_ADDR,0x00,0x03); //Release software shutdown to normal operation


  IS_IIC_WriteByte(DISPLAY_ADDR,0xFE,0xc5); //unlock FDh
  IS_IIC_WriteByte(DISPLAY_ADDR,0xFD,0x03); //Turn to page 3: function registers
  IS_IIC_WriteByte(DISPLAY_ADDR, IS31FL3736_TIME_UPDATE ,0x00);

}


uint8_t mergeValue(uint8_t initialValue, uint8_t goalValue, uint8_t buffer) {
  uint8_t result = 0x00;
  if( initialValue == goalValue) {
    result = goalValue;
  }
  if( initialValue < goalValue) {
    result = buffer + 1;
  }
  if ( initialValue > goalValue ) {
    result = buffer - 1;
  }
  return result;
}

boolean mergeValues(uint8_t *initialValue, uint8_t *goalValue, uint8_t *buffer) {
  buffer[RED_LED] = mergeValue(initialValue[RED_LED], goalValue[RED_LED], buffer[RED_LED]);
  buffer[GREEN_LED] = mergeValue(initialValue[GREEN_LED], goalValue[GREEN_LED], buffer[GREEN_LED]);
  buffer[BLUE_LED] = mergeValue(initialValue[BLUE_LED], goalValue[BLUE_LED], buffer[BLUE_LED]);

  return buffer[RED_LED] == goalValue[RED_LED] &&
         buffer[GREEN_LED] == goalValue[GREEN_LED] &&
         buffer[BLUE_LED] == goalValue[BLUE_LED];
}

void IS31FL3736_Test_rainbow(void)
{

  // uint8_t RED[3] = {0x00, 0x00, 0xFF };
  // uint8_t ORANGE[3] = {0x00, 0x00, 0xFF };
  // uint8_t YELLOW[3] = {0x00, 0x00, 0xFF };
  // uint8_t SPRING_GREEN[3] = {0x00, 0x00, 0xFF };
  // uint8_t GREEN[3] = {0x00, 0x00, 0xFF };
  // uint8_t TURQUOISE[3] = {0x00, 0x00, 0xFF };
  // uint8_t CYAN[3] = {0x00, 0x00, 0xFF };
  // uint8_t OCEAN[3] = {0x00, 0x00, 0xFF };
  // uint8_t BLUE[3] = {0x00, 0x00, 0xFF };
  // uint8_t VIOLET[3] = {0x00, 0x00, 0xFF };
  // uint8_t MAGENTA[3] = {0x00, 0x00, 0xFF };
  // uint8_t RASPBERRY[3] = {0x00, 0x00, 0xFF };


   //                          BLUE  GREEN RED
    uint8_t rainbow[12][3] = {{0x00, 0x00, 0xFF },  //Red
                              {0x00, 0x7D, 0xFF }, // Orange
                              {0x00, 0xFF, 0xFF }, // Yellow
                              {0x00, 0xFF, 0x7D }, // Spring Green
                              {0x00, 0xFF, 0x00 }, // Green
                              {0x7D, 0xFF, 0x00 }, // Turquoise
                              {0xFF, 0xFF, 0x00 }, // Cyan
                              {0xFF, 0x7D, 0x00 }, // Ocean
                              {0xFF, 0x00, 0x00 }, // Blue
                              {0xFF, 0x00, 0x7D }, // Violet
                              {0xFF, 0x00, 0xFF }, // Magenta
                              {0x7D, 0x00, 0xFF }  // Raspberry
                             };
   for ( uint8_t i=0; i<12; i++) {
     for( uint8_t j=0; j<16; j++) {
       pwm_reg[i][j] = 0x00;
     }
   }


  // For each colour, we want to transform into the next.
  uint8_t *initialValue = rainbow[RASPBERRY];
  uint8_t *goalValue;
  uint8_t current_buff[3];
  for (uint8_t colour = 0; colour < 12; colour++) {
    digitalWrite( heartbeat, !digitalRead( heartbeat) );
    goalValue = rainbow[colour];
    boolean finished = false;
    while( !finished) {
      for ( uint8_t row = 0; row < ROWS; row++) {
        for( uint8_t column = RED; column < COLUMNS; column++){
          raddr = row*3;
          caddr = column *2;
          current_buff[RED_LED] = pwm_reg[raddr + RED_LED][caddr];
          current_buff[GREEN_LED] = pwm_reg[raddr + GREEN_LED][caddr];
          current_buff[BLUE_LED] = pwm_reg[raddr + BLUE_LED][caddr];

          finished = mergeValues(initialValue, goalValue, current_buff);

          pwm_reg[raddr + RED_LED][caddr] = current_buff[RED_LED];
          pwm_reg[raddr + GREEN_LED][caddr] = current_buff[GREEN_LED];
          pwm_reg[raddr + BLUE_LED][caddr] = current_buff[BLUE_LED];

        }
      }

      IS_IIC_WriteByte(DISPLAY_ADDR,0xFE,0xc5);//unlock FDh
      IS_IIC_WriteByte(DISPLAY_ADDR,0xFD,0x01);//Turn to page 1: PWM registers
      uint8_t pwmAddr = 0;
      for ( uint8_t i=0; i<12; i++) {
        for( uint8_t j=0; j<16; j=j+2) {
          IS_IIC_WriteByte(DISPLAY_ADDR, pwmAddr, pwm_reg[i][j]);//Set PWM data to 0
          pwmAddr = pwmAddr+2;
        }
      }
      initialValue = rainbow[colour];
      delay(10);
    }
  }
}

uint16_t incrPhase(uint16_t phase) {
  uint16_t newPhase = phase + 1;
  if(newPhase > 0x5FF)
    newPhase = 0x0000;
  return newPhase;
}


void nextPhase(uint16_t *phase, uint8_t *pwm) {
  // RED
  uint16_t c_phase = phase[RED_LED];
  if ( c_phase == 0x0000 ) {
    delay(1000);
  }
  if ( c_phase == 0x0200 ) {
    delay(1000);
  }
  if ( c_phase == 0x0400 ) {
    delay(1000);
  }
  if ( 0x0000 <= c_phase &&  c_phase < 0x0100 ) {
    pwm[RED_LED] = 0xFF;
    if (pwm[GREEN_LED] < 0xFF)
      pwm[GREEN_LED]++;
    pwm[BLUE_LED] = 0x00;
  } else if ( 0x100 <= c_phase &&  c_phase < 0x0200 ) {
    if (pwm[RED_LED] > 0)
      pwm[RED_LED]--;
    pwm[GREEN_LED] = 0xFF;
    pwm[BLUE_LED] = 0x00;
  } else if ( 0x200 <= c_phase &&  c_phase < 0x0300 ) {
    pwm[RED_LED] = 0x00;
    pwm[GREEN_LED] = 0xFF;
    if (pwm[BLUE_LED] < 0xFF)
      pwm[BLUE_LED]++;
  } else if ( 0x300 <= c_phase &&  c_phase < 0x0400 ) {
    pwm[RED_LED] = 0x00;
    if (pwm[GREEN_LED] > 0)
      pwm[GREEN_LED]--;
    pwm[BLUE_LED] = 0xFF;
  } else if ( 0x400 <= c_phase &&  c_phase < 0x0500  ) {
    if (pwm[RED_LED] < 0xFF)
      pwm[RED_LED]++;
    pwm[GREEN_LED] = 0x00;
    pwm[BLUE_LED] = 0xFF;
  }  else if ( 0x500 <= c_phase ) {
    pwm[RED_LED] = 0xFF;
    pwm[GREEN_LED] = 0x00;
    if (pwm[BLUE_LED] > 0)
      pwm[BLUE_LED]--;
  }

  phase[RED_LED] = incrPhase(phase[RED_LED]);
}


void IS31FL3736_Test_rainbow_slow(void)
{

  // for ( uint8_t i=0; i<12; i++) {
  //   for( uint8_t j=0; j<16; j++) {
  //     pwm_reg[i][j] = 0x00;
  //   }
  // }
  //
  uint16_t phase[3];
  uint8_t pwm[3];
  phase[RED_LED] = 0x0000;
  phase[GREEN_LED] = 0x0000;
  phase[BLUE_LED] = 0x0000;
  pwm[RED_LED] = 0xFF;
  pwm[GREEN_LED] = 0x00;
  pwm[BLUE_LED] = 0x00;
  uint8_t raddr = 0;
  uint8_t caddr = 0;

  while(1) {
    for ( uint8_t row = 0; row < ROWS; row++) {
      for( uint8_t column = RED; column < COLUMNS; column++){
        raddr = row*3;
        caddr = column *2;

        pwm_reg[raddr + RED_LED][caddr] = pwm[RED_LED];
        pwm_reg[raddr + GREEN_LED][caddr] = pwm[GREEN_LED];
        pwm_reg[raddr + BLUE_LED][caddr] = pwm[BLUE_LED];

      }
    }
    IS_IIC_WriteByte(DISPLAY_ADDR,0xFE,0xc5);//unlock FDh
    IS_IIC_WriteByte(DISPLAY_ADDR,0xFD,0x01);//Turn to page 1: PWM registers
    uint8_t pwmAddr = 0;
    for ( uint8_t i=0; i<12; i++) {
      for( uint8_t j=0; j<16; j=j+2) {
        IS_IIC_WriteByte(DISPLAY_ADDR, pwmAddr, pwm_reg[i][j]);//Set PWM data to 0
        pwmAddr = pwmAddr+2;
      }
    }
    // delay(100);
    nextPhase(phase, pwm);
  }
}

void IS31FL3736_abm_01() {
  delay(1000);
}


void setup()
{
  Wire.begin();
  Wire.setClock(800000); //I2C 800kHz
  Serial.begin(9600);

  pinMode( heartbeat, OUTPUT);

  IS31FL3736_abm_init();

}



void loop()
{
  Serial.println("Starting loop");
  IS31FL3736_abm_01();
}

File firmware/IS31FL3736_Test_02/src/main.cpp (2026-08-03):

#include <Arduino.h>

#include<Wire.h>
#include<avr/pgmspace.h>
#define Addr_GND_GND 0xa0//AD1 open (R7 pull-low), ADDR2=GND
#define Addr_GND_VCC 0xa6//AD1 = VIO, ADDR2=GND
#define Addr_GND_SCL 0xa2//AD1 = SCL, ADDR2=GND
#define Addr_GND_SDA 0xa4//AD1 = SDA, ADDR2=GND


#define IS31FL3736_LED_RED 1
#define IS31FL3736_LED_GREEN 2
#define IS31FL3736_LED_BLUE 3

static const int heartbeat = 13;

/*
 Calculates the SW register address from the row number
 */
uint8_t IS31FL3736_row_address(int8_t row, uint8_t colour) {
  return (uint8_t) 3 * (row - 1) + colour;
}

uint8_t IS31FL3736_column_bit() {
  return -1;
}

void IS_IIC_WriteByte(uint8_t Dev_Add, uint8_t Reg_Add, uint8_t Reg_Dat)
{
  Wire.beginTransmission(Dev_Add/2); // transmit to device address
  Wire.write(Reg_Add); // sends register address
  Wire.write(Reg_Dat); // sends register data
  Wire.endTransmission(); // stop transmitting
}


void IS31FL3736_init(void)//white LED
{
  uint8_t i;
  IS_IIC_WriteByte(Addr_GND_GND,0xFE,0xc5);//Unlock FDh
  IS_IIC_WriteByte(Addr_GND_GND,0xFD,0x03);//Turn to page 3: function registers
  IS_IIC_WriteByte(Addr_GND_GND,0x00,0x00);//Enable software shutdown
  IS_IIC_WriteByte(Addr_GND_GND,0xFE,0xc5);//Unlock FDh
  IS_IIC_WriteByte(Addr_GND_GND,0xFD,0x00);// Turn to page 0: control registers
  for(i=0;i<0x18;i++) {
    IS_IIC_WriteByte(Addr_GND_GND,i,0xFF);// Enable all LEDs
  }
  //can use buffer write type as figure 7 in datasheet
  IS_IIC_WriteByte(Addr_GND_GND,0xFE,0xc5);//unlock FDh
  IS_IIC_WriteByte(Addr_GND_GND,0xFD,0x01);//Turn to page 1: PWM registers
  for(i=0;i<192;i++) {
    IS_IIC_WriteByte(Addr_GND_GND,i,0x00);//Set PWM data to 0
  }
  //can use buffer write type as figure 7 in datasheet
  IS_IIC_WriteByte(Addr_GND_GND,0xFE,0xc5);//unlock FDh
  IS_IIC_WriteByte(Addr_GND_GND,0xFD,0x03);//Turn to page 3: function registers
  IS_IIC_WriteByte(Addr_GND_GND,0x00,0x01);//Release software shutdown to normal operation
  IS_IIC_WriteByte(Addr_GND_GND,0x01,0x1f);//global current
}



void IS31FL3736_Test_mode2(void)
{
  IS_IIC_WriteByte(Addr_GND_GND,0xFE,0xc5);//unlock FDh
  IS_IIC_WriteByte(Addr_GND_GND,0xFD,0x01);//Turn to page 1: PWM registers
  for ( uint8_t pwm = 0; pwm < 0xFF; pwm++ ) {
    for(uint8_t i=0;i<192;i++) {
      IS_IIC_WriteByte(Addr_GND_GND,i, pwm);//update all PWM with 0x10
    }
    // delay(1000); // wait for a second
  }
}

void IS31FL3736_Test_mode3(void)
{
  uint8_t cs[5] = {0x00, 0x01, 0x04, 0x10, 0x40 };

  uint8_t i = 0;
  for ( uint8_t led = 0; led < 0x05; led++) {

    IS_IIC_WriteByte(Addr_GND_GND,0xFE,0xc5);//Unlock FDh
    IS_IIC_WriteByte(Addr_GND_GND,0xFD,0x00);// Turn to page 0: control registers

    for(i=0; i<0x18; i = i+2) {
      IS_IIC_WriteByte(Addr_GND_GND, i, cs[led]);//open  LED
    }

    IS_IIC_WriteByte(Addr_GND_GND,0xFE,0xc5);//unlock FDh
    IS_IIC_WriteByte(Addr_GND_GND,0xFD,0x01);//Turn to page 1: PWM registers
    for(i=0; i<192; i++) {
      IS_IIC_WriteByte(Addr_GND_GND, i, 0xA0);//Set PWM data to 0
    }

    digitalWrite( heartbeat, !digitalRead( heartbeat) );
    delay(1000); // wait for a second

  }
}

#define ROWS 12
#define COLUMNS 8
void IS31FL3736_Test_mode4(void)
{

Serial.println("TEST 4 START");
  uint16_t reg[12];
  for ( uint8_t sw=0; sw < ROWS; sw++) {
    reg[sw] = 0x0000;
  }

  IS_IIC_WriteByte(Addr_GND_GND,0xFE,0xc5);//unlock FDh
  IS_IIC_WriteByte(Addr_GND_GND,0xFD,0x01);//Turn to page 1: PWM registers
  for(uint8_t i=0; i<192; i++) {
    IS_IIC_WriteByte(Addr_GND_GND, i, 0xA0);//Set PWM data to 0
  }

  for ( uint8_t sw =0; sw < ROWS; sw++) {
    reg[sw] = 0x0001;

    IS_IIC_WriteByte(Addr_GND_GND,0xFE,0xc5); //Unlock FDh
    IS_IIC_WriteByte(Addr_GND_GND,0xFD,0x00); // Turn to page 0: control registers

    for ( uint8_t col=0; col < COLUMNS; col++) {
      // reg[sw] = 1 << col*2 | 1 >> (15);
      reg[sw] = 1 << col*2;
      uint8_t lhs = reg[sw] & 0xFF;
      uint8_t rhs = (reg[sw] >> 8) & 0xFF;

      IS_IIC_WriteByte(Addr_GND_GND, sw*2, lhs);
      IS_IIC_WriteByte(Addr_GND_GND, sw*2+1, rhs);

      delay(100);

    }
    IS_IIC_WriteByte(Addr_GND_GND, sw*2, 0x00);
    IS_IIC_WriteByte(Addr_GND_GND, sw*2+1, 0x00);
    reg[sw] = 0x0000;
  }
}



void IS31FL3736_Test_mode5(void)
{
  // uint8_t red[3] = {0xFF, 0x00, 0x00 };
  // uint8_t orange[3] = {0xFF, 0x7D, 0x00 };
  // uint8_t yellow[3] = {0xFF, 0xFF, 0x00 };
  // uint8_t springGreen [3] = {0x7D, 0xFF, 0x00 };
  // uint8_t green[3] = {0x00, 0xFF, 0x00 };
  // uint8_t turquoise[3] = {0x00, 0xFF, 0x7D };
  // uint8_t cyan[3] = {0x00, 0xFF, 0xFF };
  // uint8_t ocean[3] = {0x00, 0x7D, 0xFF };
  // uint8_t blue[3] = {0x00, 0x00, 0xFF };
  // uint8_t violet[3] = {0x7D, 0x00, 0xFF };
  // uint8_t magenta[3] = {0xFF, 0x00, 0xFF };
  // uint8_t raspberry[3] = {0x00, 0x00, 0x7D };

 //                          BLUE  GREEN RED
  uint8_t rainbow[12][3] = {{0x00, 0x00, 0xFF },  //Red
                            {0x00, 0x7D, 0xFF }, // Orange
                            {0x00, 0xFF, 0xFF }, // Yellow
                            {0x00, 0xFF, 0x7D }, // Spring Green
                            {0x00, 0xFF, 0x00 }, // Green
                            {0x7D, 0xFF, 0x00 }, // Turquoise
                            {0xFF, 0xFF, 0x00 }, // Cyan
                            {0xFF, 0x7D, 0x00 }, // Ocean
                            {0xFF, 0x00, 0x00 }, // Blue
                            {0xFF, 0x00, 0x7D }, // Violet
                            {0xFF, 0x00, 0xFF }, // Magenta
                            {0x7D, 0x00, 0xFF }  // Raspberry
                           };

  uint8_t pwm_reg[12][16];
  // for ( uint8_t i=0; i<12; i++) {
  //   for( uint8_t j=0; j<16; j++) {
  //     pwm_reg[i][j] = 0x00;
  //   }
  // }

  for (uint8_t colour = 0; colour<12; colour++){
    for ( uint8_t row = 0; row < 4; row++){
      for( uint8_t column = 0; column < 16; column=column+2){
        pwm_reg[row*3][column] = rainbow[colour][0];
        pwm_reg[row*3+1][column] = rainbow[colour][1];
        pwm_reg[row*3+2][column] = rainbow[colour][2];
      }
    }

    IS_IIC_WriteByte(Addr_GND_GND,0xFE,0xc5);//unlock FDh
    IS_IIC_WriteByte(Addr_GND_GND,0xFD,0x01);//Turn to page 1: PWM registers
    uint8_t pwmAddr = 0;
    for ( uint8_t i=0; i<12; i++) {
      for( uint8_t j=0; j<16; j=j+2) {
        IS_IIC_WriteByte(Addr_GND_GND, pwmAddr, pwm_reg[i][j]);//Set PWM data to 0
        pwmAddr = pwmAddr+2;
      }
    }
    delay(100);
  }
  // delay(1000);
}
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

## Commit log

2019-12-31 Schematic and initial layout
    [IS31FL3736_Dev.kicad_pcb, IS31FL3736_Dev.sch]
2020-01-27 Board update
    [IS31FL3736_Dev.kicad_pcb]
2020-04-05 Layout done
    [AAA3528.FCStd, AAA3528.IGS, AAA3528.sldprt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]
2020-10-04 Update to SBD pullup
    [IS31FL3736_Dev.kicad_pcb, IS31FL3736_Dev.sch]
2026-08-03 Update last changes
    [AAA3528.IGS, IS31FL3736_Dev.kicad_pcb, IS31FL3736_Dev.sch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]
2026-08-03 Archived for KiCad 5.0.1
    [IS31FL3736_Dev.sch]
2026-08-03 Upgraded to kicad release 10.0.2
    [IS31FL3736_Dev.kicad_pcb, IS31FL3736_Dev.kicad_sch]
2026-08-03 Schematic as PDF
    [IS31FL3736_Dev.kicad_sch]
2026-08-03 Dropped connections after upgrade
    [IS31FL3736_Dev.kicad_sch]
